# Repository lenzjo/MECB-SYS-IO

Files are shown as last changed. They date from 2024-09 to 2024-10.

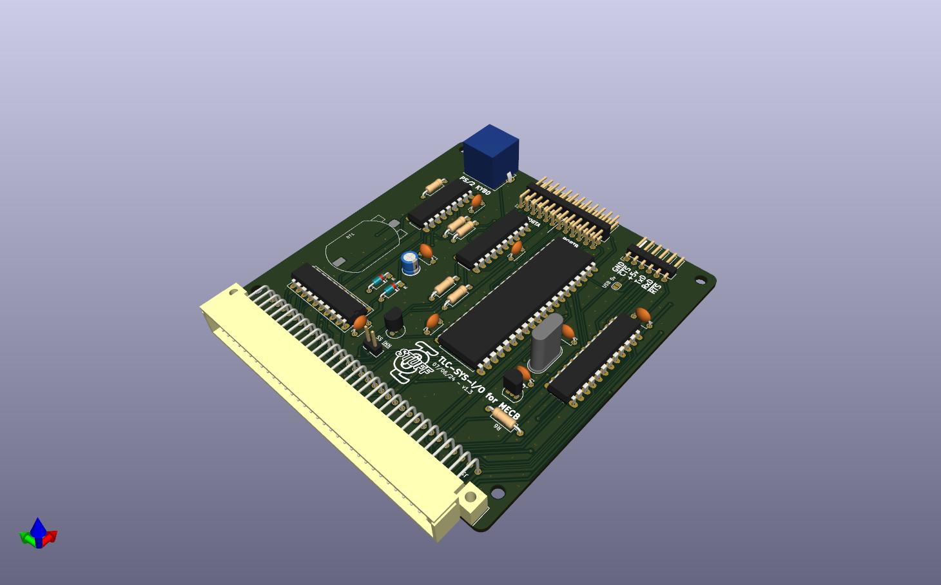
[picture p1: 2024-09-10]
TLC-SYS-IO.jpg

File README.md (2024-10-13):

# TLC SYS-IO for MECB

This board consists of the following:

- SCC2691 ACIA

- WDC6522N

- RTC72421 - with battery backup

- ATTINY261A-P -for PS/2 Keyboard

I have brought out all available outputs along the top of the PCB, however, the PS/2 clock and data signals are also on the connector (pins C11 and A12 repectively) as are TxD (A16), RxD (A17), RTS (C16) and CTS (C19).

Use at your own risk as I have not had time yet to fully test the PCB. 

Also, the battery holder is an SMD part. It's easy enough to attach, I used a heat gun from underneath the pcb.

UPDATES

1.3 - Fixed Reset line on SCC2691, updated battery holder.

1.4 - Fixed KYBD clk line.

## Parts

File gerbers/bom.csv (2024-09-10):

Designator | Footprint | Quantity | Value | LCSC Part #
BT1 | SMD CR2032 | 1 | Battery_Cell
C1, C2 | C_Disc_D4.7mm_W2.5mm_P5.00mm | 2 | 22pF
C3, C4, C5, C6, C7 | C_Disc_D4.7mm_W2.5mm_P5.00mm | 5 | 100nF
C8 | CP_Radial_D5.0mm_P2.50mm | 1 | 1uF
C9 | C_Disc_D5.1mm_W3.2mm_P5.00mm | 1 | 100nF
D1, D2 | D_DO-35_SOD27_P7.62mm_Horizontal | 2 | BAT42
H1, H2, H3, H4 | MountingHole_3.2mm_M3 | 4 | MountingHole
J1 | DIN41612_C_2x32_C64AC_Male_Horizontal_THT | 1 | MECB_64AC
J2 | PS2_mini_DIN | 1 | PS/2_Connector
J6 | PinHeader_2x12_P2.54mm_Horizontal | 1 | Conn_02x12_Odd_Even
JP1 | PinHeader_1x02_P2.54mm_Vertical | 1 | ~{NMI} SS
JP2 | SolderJumper-2_P1.3mm_Open_RoundedPad1.0x1.5mm | 1 | USB 5v
L1 | Logo11x13 | 1 | myLogo
P1 | PinHeader_1x06_P2.54mm_Horizontal | 1 | FTDI_con
Q1 | TO-92_Inline | 1 | 2N7000
Q2 | TO-92_Inline | 1 | 2N7000 | 2N7000
R1, R2 | R_Axial_DIN0207_L6.3mm_D2.5mm_P10.16mm_Horizontal | 2 | 10K
R3 | R_Axial_DIN0207_L6.3mm_D2.5mm_P10.16mm_Horizontal | 1 | 3K3
R4, R5 | R_Axial_DIN0207_L6.3mm_D2.5mm_P10.16mm_Horizontal | 2 | 1K
R6 | R_Axial_DIN0207_L6.3mm_D2.5mm_P10.16mm_Horizontal | 1 | 1M
U1 | DIP-20_W7.62mm_Socket_LongPads | 1 | ATF16V8
U2 | DIP-18_W7.62mm_LongPads | 1 | RTC72421
U4 | DIP-24_W7.62mm_LongPads | 1 | SCC2691
U5 | DIP-40_W15.24mm_LongPads | 1 | WD65C22
U6 | DIP-20_W7.62mm_LongPads | 1 | ATtiny261A-P
Y1 | Crystal_HC49-U_Vertical | 1 | 3.6864Mhz

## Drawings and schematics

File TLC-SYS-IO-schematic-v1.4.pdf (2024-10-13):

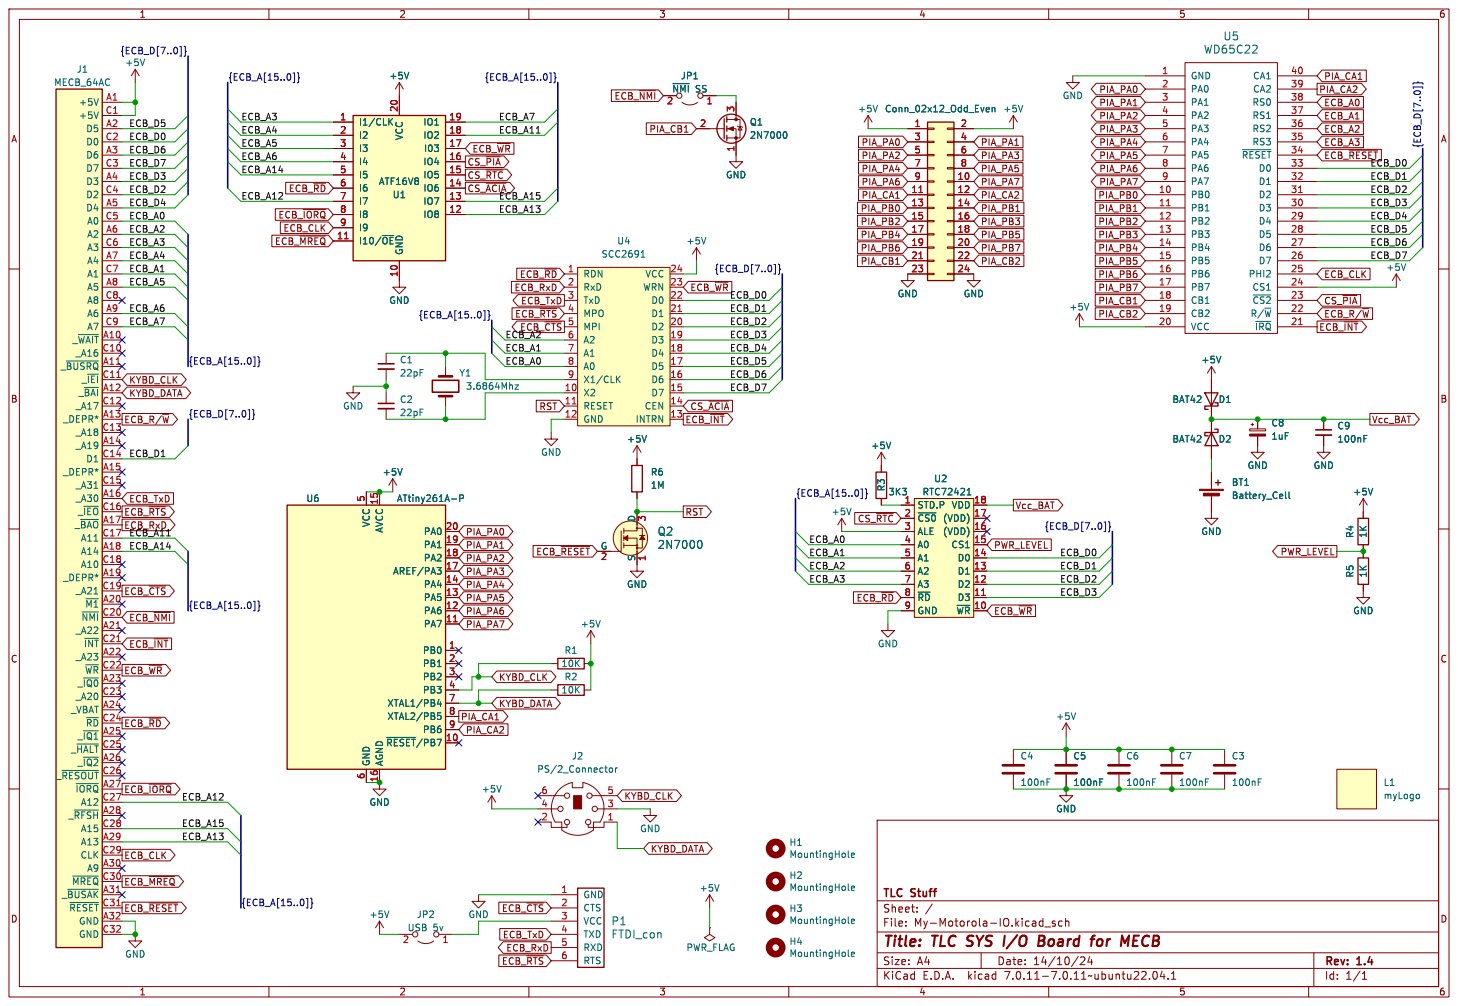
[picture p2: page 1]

(VDD) 17 VDD 18 ~{CS0} 2 ALE 3 A0 4 A1 5 A2 6 A3 7 ~{RD} 8 GND 9 +5VR3 3K3 Conn_02x12_Odd_Even

File: My-Motorola-IO.kicad_sch Sheet: / TLC Stuff +5V

Id: 1/1 Title: TLC SYS I/O Board for MECB

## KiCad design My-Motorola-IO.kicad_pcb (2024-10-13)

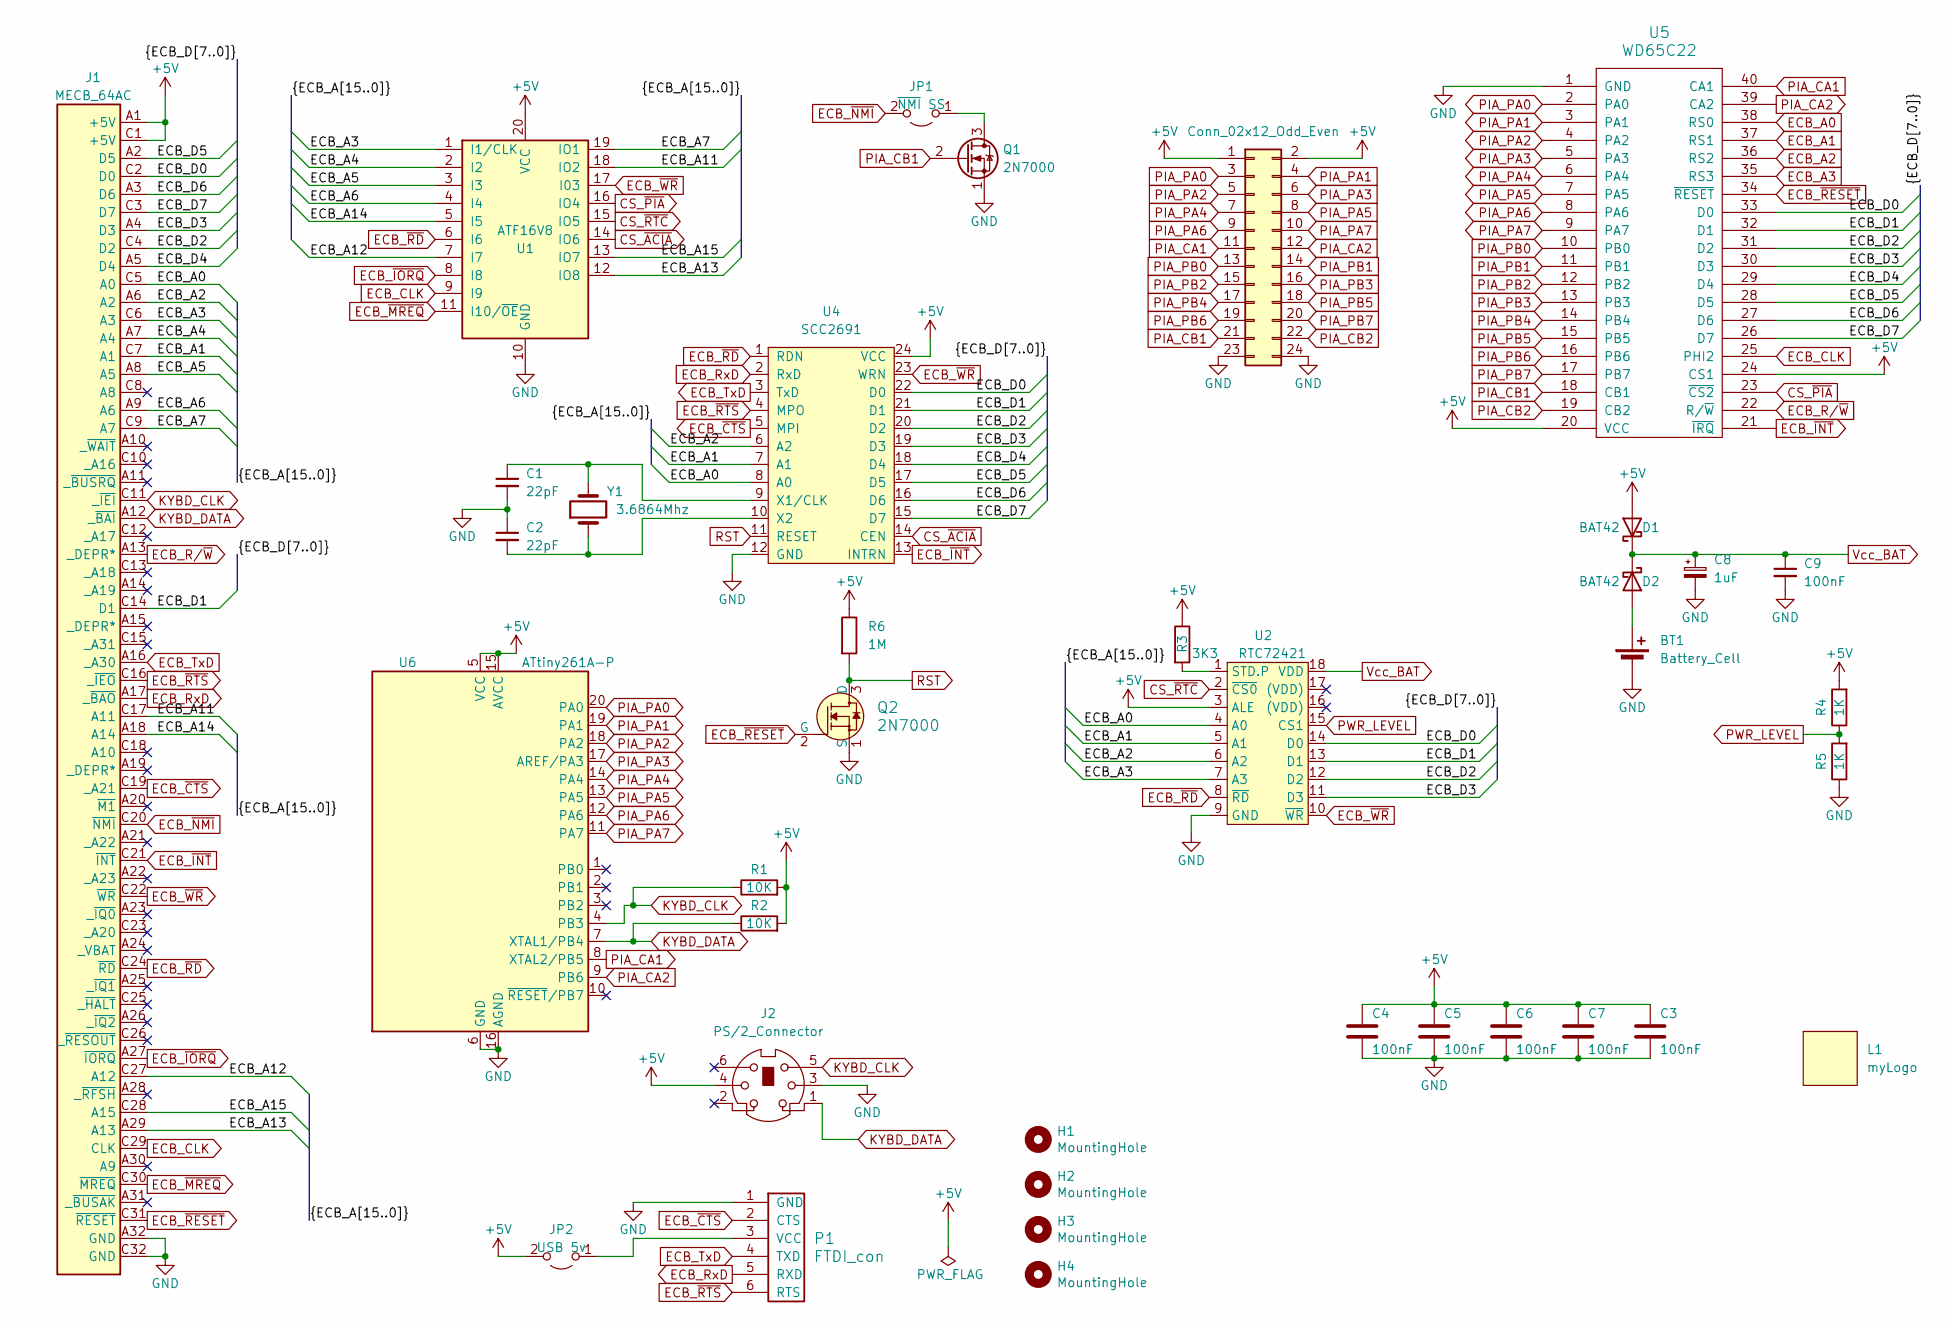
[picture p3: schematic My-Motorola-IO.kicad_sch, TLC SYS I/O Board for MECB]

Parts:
BT1: Battery_Cell; SMD CR2032
C1, C2: 22pF; C_Disc_D4.7mm_W2.5mm_P5.00mm
C3, C4, C5, C6, C7: 100nF; C_Disc_D4.7mm_W2.5mm_P5.00mm
C8: 1uF; CP_Radial_D5.0mm_P2.50mm
C9: 100nF; C_Disc_D5.1mm_W3.2mm_P5.00mm
D1, D2: BAT42; D_DO-35_SOD27_P7.62mm_Horizontal
H1, H2, H3, H4: MountingHole; MountingHole_3.2mm_M3
J1: MECB_64AC; DIN41612_C_2x32_C64AC_Male_Horizontal_THT
J2: PS/2_Connector; PS2_mini_DIN
J6: Conn_02x12_Odd_Even; PinHeader_2x12_P2.54mm_Horizontal
JP1: ~{NMI} SS; PinHeader_1x02_P2.54mm_Vertical
JP2: USB 5v; SolderJumper-2_P1.3mm_Open_RoundedPad1.0x1.5mm
L1: myLogo; Logo11x13
P1: FTDI_con; PinHeader_1x06_P2.54mm_Horizontal
Q1: 2N7000; TO-92_Inline
Q2: 2N7000; TO-92_Inline; MPN 2N7000; Digi-Key_PN 2N7000FS-ND
R1, R2: 10K; R_Axial_DIN0207_L6.3mm_D2.5mm_P10.16mm_Horizontal
R3: 3K3; R_Axial_DIN0207_L6.3mm_D2.5mm_P10.16mm_Horizontal
R4, R5: 1K; R_Axial_DIN0207_L6.3mm_D2.5mm_P10.16mm_Horizontal
R6: 1M; R_Axial_DIN0207_L6.3mm_D2.5mm_P10.16mm_Horizontal
U1: ATF16V8; DIP-20_W7.62mm_Socket_LongPads
U2: RTC72421; DIP-18_W7.62mm_LongPads
U4: SCC2691; DIP-24_W7.62mm_LongPads
U5: WD65C22; DIP-40_W15.24mm_LongPads
U6: ATtiny261A-P; DIP-20_W7.62mm_LongPads
Y1: 3.6864Mhz; Crystal_HC49-U_Vertical

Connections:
+5V: C3.1, C4.1, C5.1, C6.1, C7.1, D1.2 (A), J1.A1 (+5V), J1.C1 (+5V), J2.4, J6.1, J6.2, JP2.2 (B), R1.2, R2.2, R3.1, R4.2, R6.1, U1.20 (VCC), U2.3 (ALE), U4.24 (VCC), U5.20 (VCC), U5.24 (CS1), U6.5 (VCC), U6.15 (AVCC)
/ECB_A4: J1.A7 (A4), U1.2 (I2)
/ECB_A5: J1.A8 (A5), U1.3 (I3)
/ECB_A6: J1.A9 (A6), U1.4 (I4)
/ECB_A7: J1.C9 (A7), U1.19 (IO1)
/ECB_A11: J1.C17 (A11), U1.18 (IO2)
/ECB_A12: J1.C27 (A12), U1.7 (I7)
/ECB_A13: J1.A29 (A13), U1.12 (IO8)
/ECB_A14: J1.A18 (A14), U1.5 (I5)
/ECB_A15: J1.C28 (A15), U1.13 (IO7)
/ECB_D0: J1.C2 (D0), U2.14 (D0), U4.22 (D0), U5.33 (D0)
/ECB_D1: J1.C14 (D1), U2.13 (D1), U4.21 (D1), U5.32 (D1)
/ECB_D2: J1.C4 (D2), U2.12 (D2), U4.20 (D2), U5.31 (D2)
/ECB_D3: J1.A4 (D3), U2.11 (D3), U4.19 (D3), U5.30 (D3)
/ECB_D4: J1.A5 (D4), U4.18 (D4), U5.29 (D4)
/ECB_D5: J1.A2 (D5), U4.17 (D5), U5.28 (D5)
/ECB_D6: J1.A3 (D6), U4.16 (D6), U5.27 (D6)
/ECB_D7: J1.C3 (D7), U4.15 (D7), U5.26 (D7)
CS_~ACIA: U1.14 (IO6), U4.14 (CEN)
CS_~PIA: U1.16 (IO4), U5.23 (~CS2)
CS_~RTC: U1.15 (IO5), U2.2 (~CS0)
ECB_A0: J1.C5 (A0), U2.4 (A0), U4.8 (A0), U5.38 (RS0)
ECB_A1: J1.C7 (A1), U2.5 (A1), U4.7 (A1), U5.37 (RS1)
ECB_A2: J1.A6 (A2), U2.6 (A2), U4.6 (A2), U5.36 (RS2)
ECB_A3: J1.C6 (A3), U1.1 (I1/CLK), U2.7 (A3), U5.35 (RS3)
ECB_CLK: J1.C29 (CLK), U1.9 (I9), U5.25 (PHI2)
ECB_RxD: J1.A17 (_~BAO), P1.5 (RXD), U4.2 (RxD)
ECB_R/~W: J1.A13 (_DEPR*), U5.22 (R/~W)
ECB_TxD: J1.A16 (_A30), P1.4 (TXD), U4.3 (TxD)
ECB_~CTS: J1.C19 (_A21), P1.2 (CTS), U4.5 (MPI)
ECB_~INT: J1.C21 (~INT), U4.13 (INTRN), U5.21 (~IRQ)
ECB_~IORQ: J1.A27 (~IORQ), U1.8 (I8)
ECB_~MREQ: J1.C30 (~MREQ), U1.11 (I10/~OE)
ECB_~NMI: J1.C20 (~NMI), JP1.2 (B)
ECB_~RD: J1.C24 (~RD), U1.6 (I6), U2.8 (~RD), U4.1 (RDN)
ECB_~RESET: J1.C31 (~RESET), Q2.2 (G), U5.34 (~RESET)
ECB_~RTS: J1.C16 (_~IEO), P1.6 (RTS), U4.4 (MPO)
ECB_~WR: J1.C22 (~WR), U1.17 (I03), U2.10 (~WR), U4.23 (WRN)
GND: BT1.2 (-), C1.2, C2.1, C3.2, C4.2, C5.2, C6.2, C7.2, C8.2, C9.2, J1.A32 (GND), J1.C32 (GND), J2.3, J6.23, J6.24, P1.1 (GND), Q1.1 (S), Q2.1 (S), R5.1, U1.10 (GND), U2.9 (GND), U4.12 (GND), U5.1 (GND), U6.6 (GND), U6.16 (AGND)
KYBD_CLK: J1.C11 (_~IEI), J2.5, R1.1, U6.4 (PB3)
KYBD_DATA: J1.A12 (_~BAI), J2.1, R2.1, U6.7 (XTAL1/PB4)
unnamed: BT1.1 (+), D2.2 (A)
unnamed: JP1.1 (A), Q1.3 (D)
unnamed: JP2.1 (A), P1.3 (VCC)
unnamed: R3.2, U2.1 (STD.P)
unnamed: C1.1, U4.9 (X1/CLK), Y1.2
unnamed: C2.2, U4.10 (X2), Y1.1
PIA_CA1: J6.11, U5.40 (CA1), U6.8 (XTAL2/PB5)
PIA_CA2: J6.12, U5.39 (CA2), U6.9 (PB6)
PIA_CB1: J6.21, Q1.2 (G), U5.18 (CB1)
PIA_CB2: J6.22, U5.19 (CB2)
PIA_PA0: J6.3, U5.2 (PA0), U6.20 (PA0)
PIA_PA1: J6.4, U5.3 (PA1), U6.19 (PA1)
PIA_PA2: J6.5, U5.4 (PA2), U6.18 (PA2)
PIA_PA3: J6.6, U5.5 (PA3), U6.17 (AREF/PA3)
PIA_PA4: J6.7, U5.6 (PA4), U6.14 (PA4)
PIA_PA5: J6.8, U5.7 (PA5), U6.13 (PA5)
PIA_PA6: J6.9, U5.8 (PA6), U6.12 (PA6)
PIA_PA7: J6.10, U5.9 (PA7), U6.11 (PA7)
PIA_PB0: J6.13, U5.10 (PB0)
PIA_PB1: J6.14, U5.11 (PB1)
PIA_PB2: J6.15, U5.12 (PB2)
PIA_PB3: J6.16, U5.13 (PB3)
PIA_PB4: J6.17, U5.14 (PB4)
PIA_PB5: J6.18, U5.15 (PB5)
PIA_PB6: J6.19, U5.16 (PB6)
PIA_PB7: J6.20, U5.17 (PB7)
PWR_LEVEL: R4.1, R5.2, U2.15 (CS1)
RST: Q2.3 (D), R6.2, U4.11 (RESET)
Vcc_BAT: C8.1, C9.1, D1.1 (K), D2.1 (K), U2.18 (VDD)

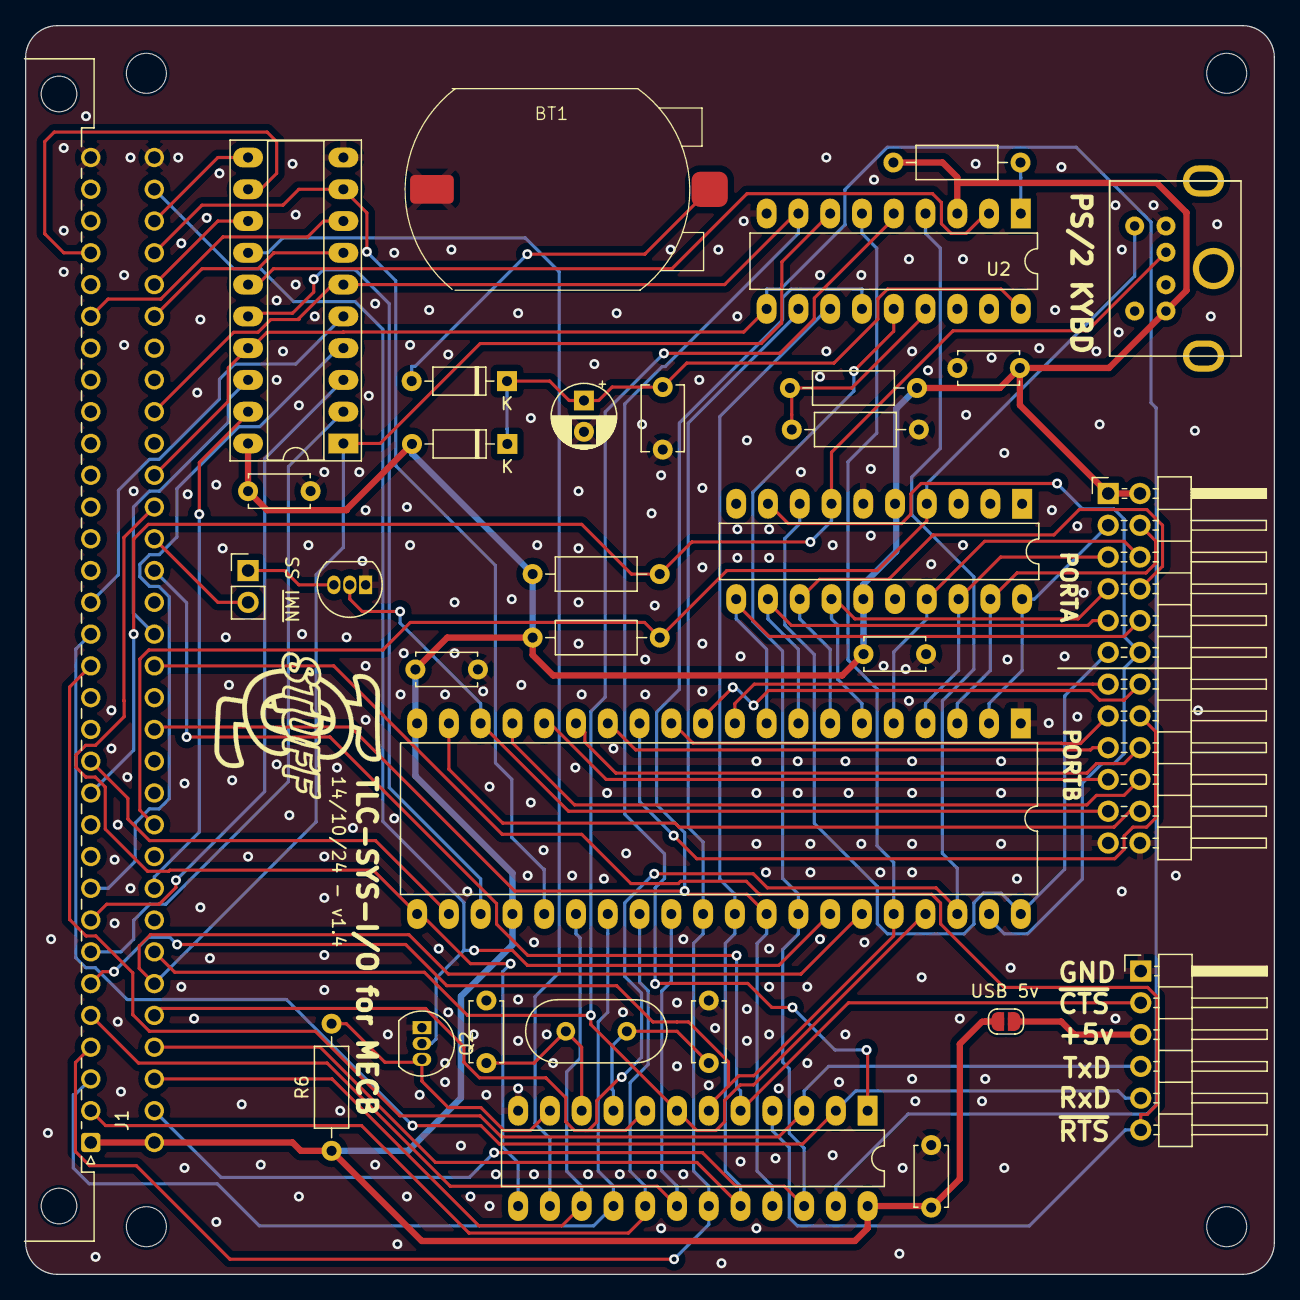
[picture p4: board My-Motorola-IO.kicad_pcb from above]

Board: 2 copper layers, 99.8 x 99.8 mm, 37 parts (0 on the bottom side), 70 nets.

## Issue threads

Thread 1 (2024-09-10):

SCC2691 reset polarity

DavidJRichards, 2024-09-10:
Greetings, There appears to be a discrepancy between the reset polarities of the MECB bus and the requirement of the SCC2691. The bus reset is active low but the SCC2691 reset input is active high. Have I misunderstood the documents or is this a schematic error? I have yet to test this on any hardware but am looking forward to trying your board sortly. Best regards, David.

lenzjo, 2024-09-10:
Sorry about that. Typical schoolboy error. I have updated the repository with an untested fix, but it should work.

DavidJRichards, 2024-09-16:
Thanks for the updated files. The value of R6, 1M ohm,  on the updated schematic seems high. I would expect to see something around a few K ohms in that position. D

lenzjo, 2024-09-17:
1M has worked for me in the past on different projects. I have yet to try it in this instance as I am waiting for the PCBs. As I said in the README, I have not had time to fully test the pcb yet as I have little free time.

Closed 2024-09-17.

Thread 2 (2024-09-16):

Keyboard connector signal pin holes size

DavidJRichards, 2024-09-16:
The mini DIN connectors I have seen have small flat pins which are larger than the holes on the PCB. Drilling out to suit these could result in another problem since a PCB track is routed in the space between the pins holes. However, although tight the pins just fit as is.

lenzjo, 2024-09-17:
I get my mini DIN connectors from [ebay](https://www.ebay.co.uk/itm/384011894850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). Or just do a search for mini DIN pcb connector. The footprint I used was from the standard Kicad library.

Closed 2024-09-17.

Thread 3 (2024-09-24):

Uses undocumented connector pin A13 for read/write signal

DavidJRichards, 2024-09-24:
This board depends on bus signal A13 for Read / Write signal to the 6522 VIA
This pin is not implemented in the MECB
Is the intention to patch through the CPU R/W signal for use here?
Would it be possible to use the ECB!WR here instead?

lenzjo, 2024-09-24:
"This board depends on bus signal A13 for Read / Write signal to the 6522 VIA"
Correct

"This pin is not implemented in the MECB"
Correct, but my boards are to be used with MY [version](https://github.com/lenzjo/MECB-Backplane) of the MECB back-plane which also implements:
C11 - KYBD_CLK
A12 - KYBD_DATA
A30 - ECB_TxD
C16 - ECB_RTS
A17 - ECB_RxD
C19 - ECB_CTS
A28 - COMP_VID
A31 - SND

"Is the intention to patch through the CPU R/W signal for use here?"
Yes, if you are not using my [backplane](https://github.com/lenzjo/MECB-Backplane)

"Would it be possible to use the ECB!WR here instead?"
Probably

Closed 2024-09-24.

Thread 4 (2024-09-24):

Board power track defect

DavidJRichards, 2024-09-24:
Greetings, I found a problem, not sure of the cause.

The SYS-IO board I had made from gerbers dated 19th July 2024 suffers from a problem where some of the nodes which should connect to +5V are not connected to the main 5V power input connector.

These nodes are all connected together but not to +5V incoming:
D1 anode
U1 pin 20
U5 pin 20
U5 pin 24
R1 +Ve
R2 +ve
Cx +ve
Cx +ve

It appears that a track is missing rather than a broken connection but I can't be sure not having seen the track layout in the cad system. All five boards I have seem to have the same problem.
Other connections seem ok, VIA now works with incoming DC applied with bodge wire.

Best regards, David.

lenzjo, 2024-09-25:
Missing trace: ATtiny261A - U6 pin 15 -> C4 pin 1 +5v. That will connect all of the above to +5v.

FYI: There has been at least one, maybe two updates since the 19th July, fixing stuff. One that springs to mind is the GND on the battery was not connected to GND.

Closed 2024-09-25.

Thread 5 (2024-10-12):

Keyboard clock signal routing error

DavidJRichards, 2024-10-12:
The keyboard clock signal is connected to the ATtiny261A BP2 (pin3) the supplied firmware is expecting the keyboard clock on PB3 (pin 4)

A simple fix for this problem is to connect pins 3 & 4 though a better solution is to isolate PB2 and re-route the clock and pull-up resistor freeing PB2 for other uses.

No signals were being received before making this change.
To test the keyboard it is adequate to connect PIA_CA1 with PIA_CA2 to supply the necessary handshake.
hth David.

lenzjo, 2024-10-15:
Thank you David, I've updated the gerbers etc.

Closed 2024-10-15.

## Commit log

2024-09-10 updated SCC2691 reset line and battery holder
    [My-Motorola-IO.kicad_sch, bom.csv]
2024-10-13 KEYBD clk fixed, added missing pwr trace
    [My-Motorola-IO.kicad_pcb, My-Motorola-IO.kicad_sch]
